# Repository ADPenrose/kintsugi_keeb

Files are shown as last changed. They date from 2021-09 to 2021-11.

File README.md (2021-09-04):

# KINTSUGI
Repository for the kintsugi keyboard.

## Licence
  
Kintsugi is [licenced](LICENSE) under the [Creative Commons Attribution-NonCommercial 4.0 International License](https://creativecommons.org/licenses/by-nc/4.0/).  

This PCB design may be freely reproduced, modified, and manufactured for **PERSONAL USE ONLY** and may not be reproduced in physical form for public sale without the knowledge and permission of me, the desiger of the keyboard. 

That is to say, if you want to run a a public groupbuy, the non-commercial clause can be waived. For that to happen, please contact me at mysticmetromx@gmail.com.

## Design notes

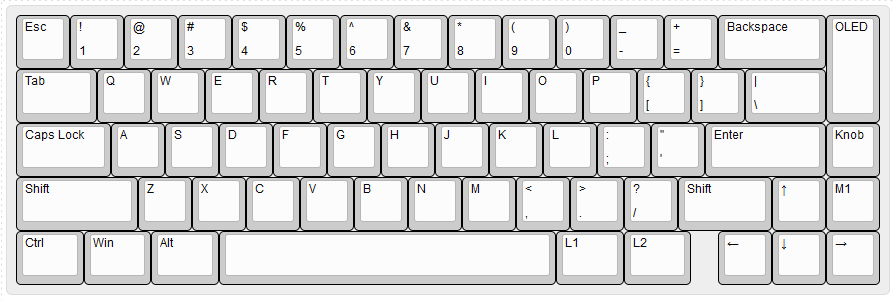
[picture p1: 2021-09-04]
images/Layout.PNG

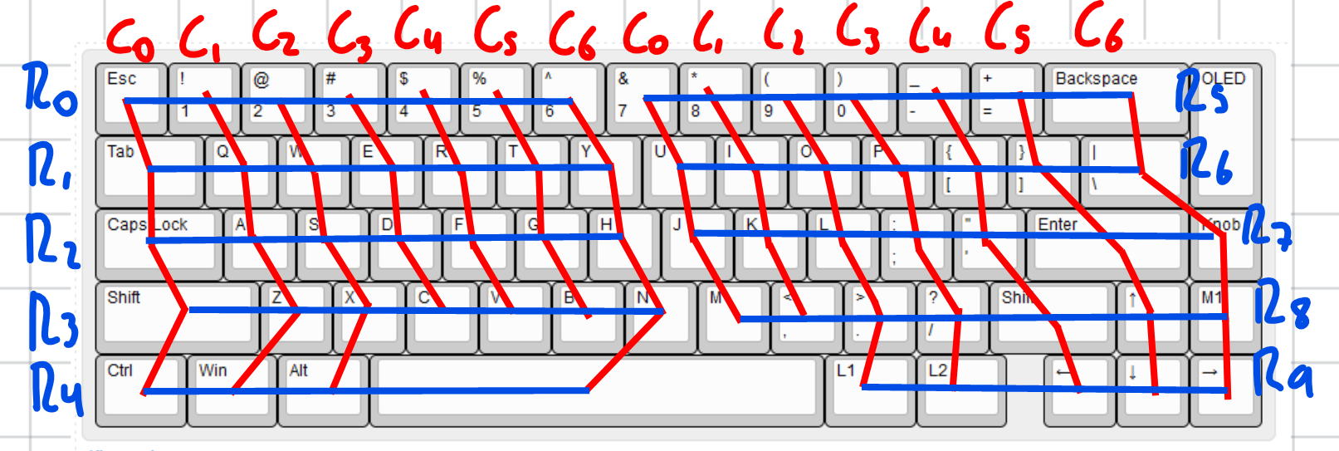
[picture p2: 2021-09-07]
images/Matrix.PNG

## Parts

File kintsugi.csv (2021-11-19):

Id | Designator | Package | Quantity | Designation | Supplier and ref
1 | G*** | LogoKC1 | 1 | LOGO
2 | MX28,MX15 | MXOnly-1.5U-Hotswap | 2 | MX-NoLED
3 | MX39,MX48,MX5,MX1,MX52,MX27,MX13,MX26,MX40,MX55,MX64,MX63,MX62,MX54,MX51,MX50,MX49,MX47,MX46,MX45,MX44,MX43,MX38,MX37,MX36,MX35,MX34,MX33,MX32,MX31,MX30,MX25,MX24,MX23,MX22,MX21,MX20,MX19,MX18,MX17,MX16,MX12,MX11,MX10,MX9,MX8,MX7,MX6,MX4,MX3,MX2 | MXOnly-1U-Hotswap | 51 | MX-NoLED
4 | MX41,MX42 | MXOnly-2.25U-Hotswap | 2 | MX-NoLED
5 | MX53,MX29 | MXOnly-1.75U-Hotswap | 2 | MX-NoLED
6 | MX14 | MXOnly-2U-Hotswap | 1 | MX-NoLED
7 | D54,D53,D28,D27,D14,D13,D15,D65,D64,D63,D62,D61,D60,D59,D58,D57,D56,D55,D52,D51,D50,D49,D48,D47,D46,D45,D44,D43,D42,D41,D40,D39,D38,D37,D36,D35,D34,D33,D32,D31,D30,D29,D26,D25,D24,D23,D22,D21,D20,D19,D18,D17,D16,D12,D11,D10,D9,D8,D7,D6,D5,D4,D3,D2,D1 | Diode-dual-onesided | 65 | D_Small
8 | J1 | PinHeader_1x04_P2.54mm_Vertical | 1 | Conn_01x04
9 | MX58,MX61,MX60,MX57,MX56 | MXOnly-1.25U-Hotswap | 5 | MX-NoLED
10 | MX59 | MXOnly-6.25U-Hotswap-ReversedStabilizers | 1 | MX-NoLED
11 | U1 | Elite-C | 1 | Elite-C
12 | SW1 | RotaryEncoder_Alps_EC11E-Switch_Vertical_H20mm | 1 | Rotary_Encoder_Switch
13 | D81,D80,D79,D78,D77,D76,D75,D74,D73,D72,D71,D70,D69,D68,D67,D66 | LED_WS2812B_PLCC4_5.0x5.0mm_P3.2mm | 16 | WS2812B
14 | C16,C15,C14,C13,C12,C11,C10,C9,C8,C7,C6,C5,C4,C3,C2,C1 | C_0805_2012Metric_Pad1.18x1.45mm_HandSolder | 16 | 100n

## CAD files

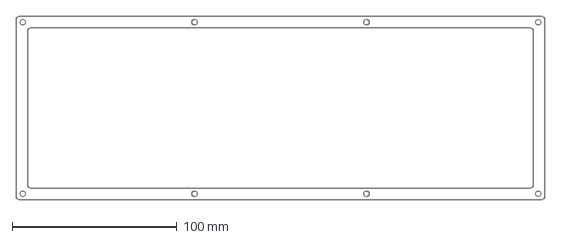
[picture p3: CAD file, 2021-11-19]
acrylic_case/DXF/kintsugi_closed_upper.dxf
320.8 x 111.2 mm

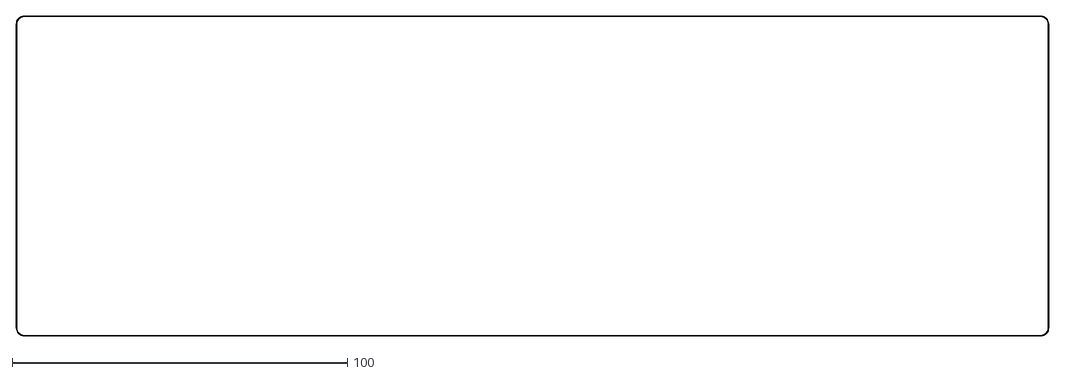
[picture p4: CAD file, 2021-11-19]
dfx/kintsugi-Edge_Cuts.dxf
308.0 x 95.3

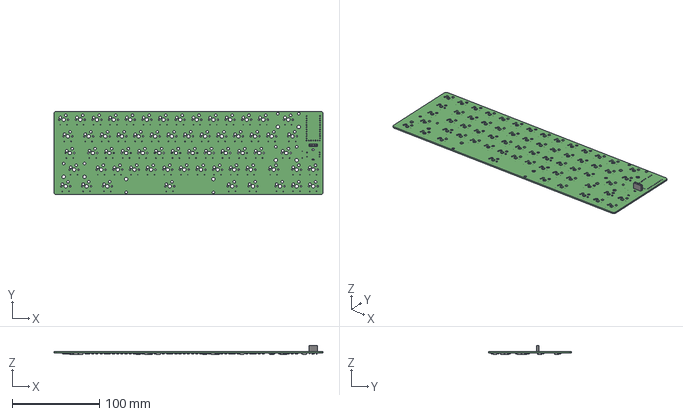
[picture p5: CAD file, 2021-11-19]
kintsugi.step
308.0 x 95.2 x 10.3 mm

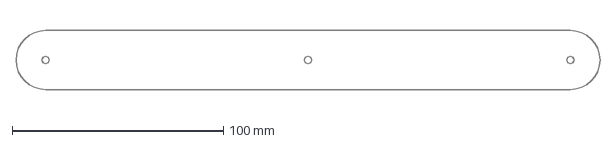
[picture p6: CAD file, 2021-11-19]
acrylic_case/DXF/kintsugi_foot_1.dxf
276.5 x 28.0 mm

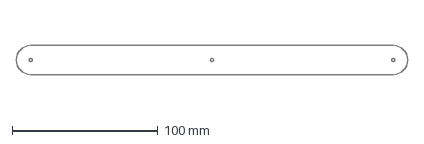
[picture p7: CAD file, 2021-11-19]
acrylic_case/DXF/kintsugi_foot_3.dxf
268.5 x 20.0 mm

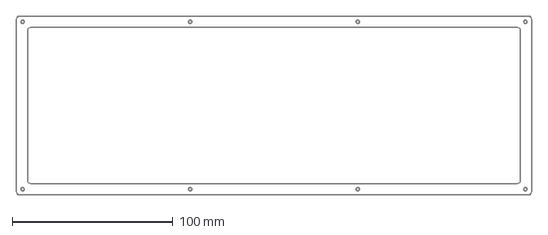
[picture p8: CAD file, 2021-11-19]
acrylic_case/DXF/kintsugi_top.dxf
320.8 x 111.2 mm

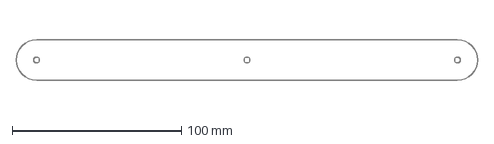
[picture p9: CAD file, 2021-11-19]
acrylic_case/DXF/kintsugi_foot_2.dxf
272.5 x 24.0 mm

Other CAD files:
acrylic_case/DWG/kintsugi_closed_lower.dwg
acrylic_case/HSMCU/3mm_acrilico_azul_pastel.dwg
acrylic_case/Para corte/2_3mm_acrilico_espejo_dorado.dwg
acrylic_case/DWG/kintsugi_open_upper.dwg
acrylic_case/HSMCU/1.5mm_bicolam_abs_blanco.dwg
acrylic_case/Para corte/5_3mm_acrilico_cristal_mate.dwg
acrylic_case/DWG/Kintsugi_case.dwg
acrylic_case/Para corte/7_3mm_acrilico_cristal_mate.dwg
acrylic_case/DWG/kintsugi_plate.dwg
acrylic_case/Para corte/3_1.5mm_bicolam_abs_negro.dwg
acrylic_case/DWG/kintsugi_bottom.dwg
acrylic_case/DWG/kintsugi_closed_upper.dwg
acrylic_case/DWG/kintsugi_foot_1.dwg
acrylic_case/DWG/kintsugi_foot_2.dwg
acrylic_case/DWG/kintsugi_foot_3.dwg
acrylic_case/DWG/kintsugi_open_lower.dwg
acrylic_case/DWG/kintsugi_top.dwg
acrylic_case/DXF/kintsugi_open_lower.dxf
acrylic_case/Para corte/1_3mm_acrilico_cristal_mate.dwg
acrylic_case/Para corte/4_3mm_acrilico_cristal_mate.dwg
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

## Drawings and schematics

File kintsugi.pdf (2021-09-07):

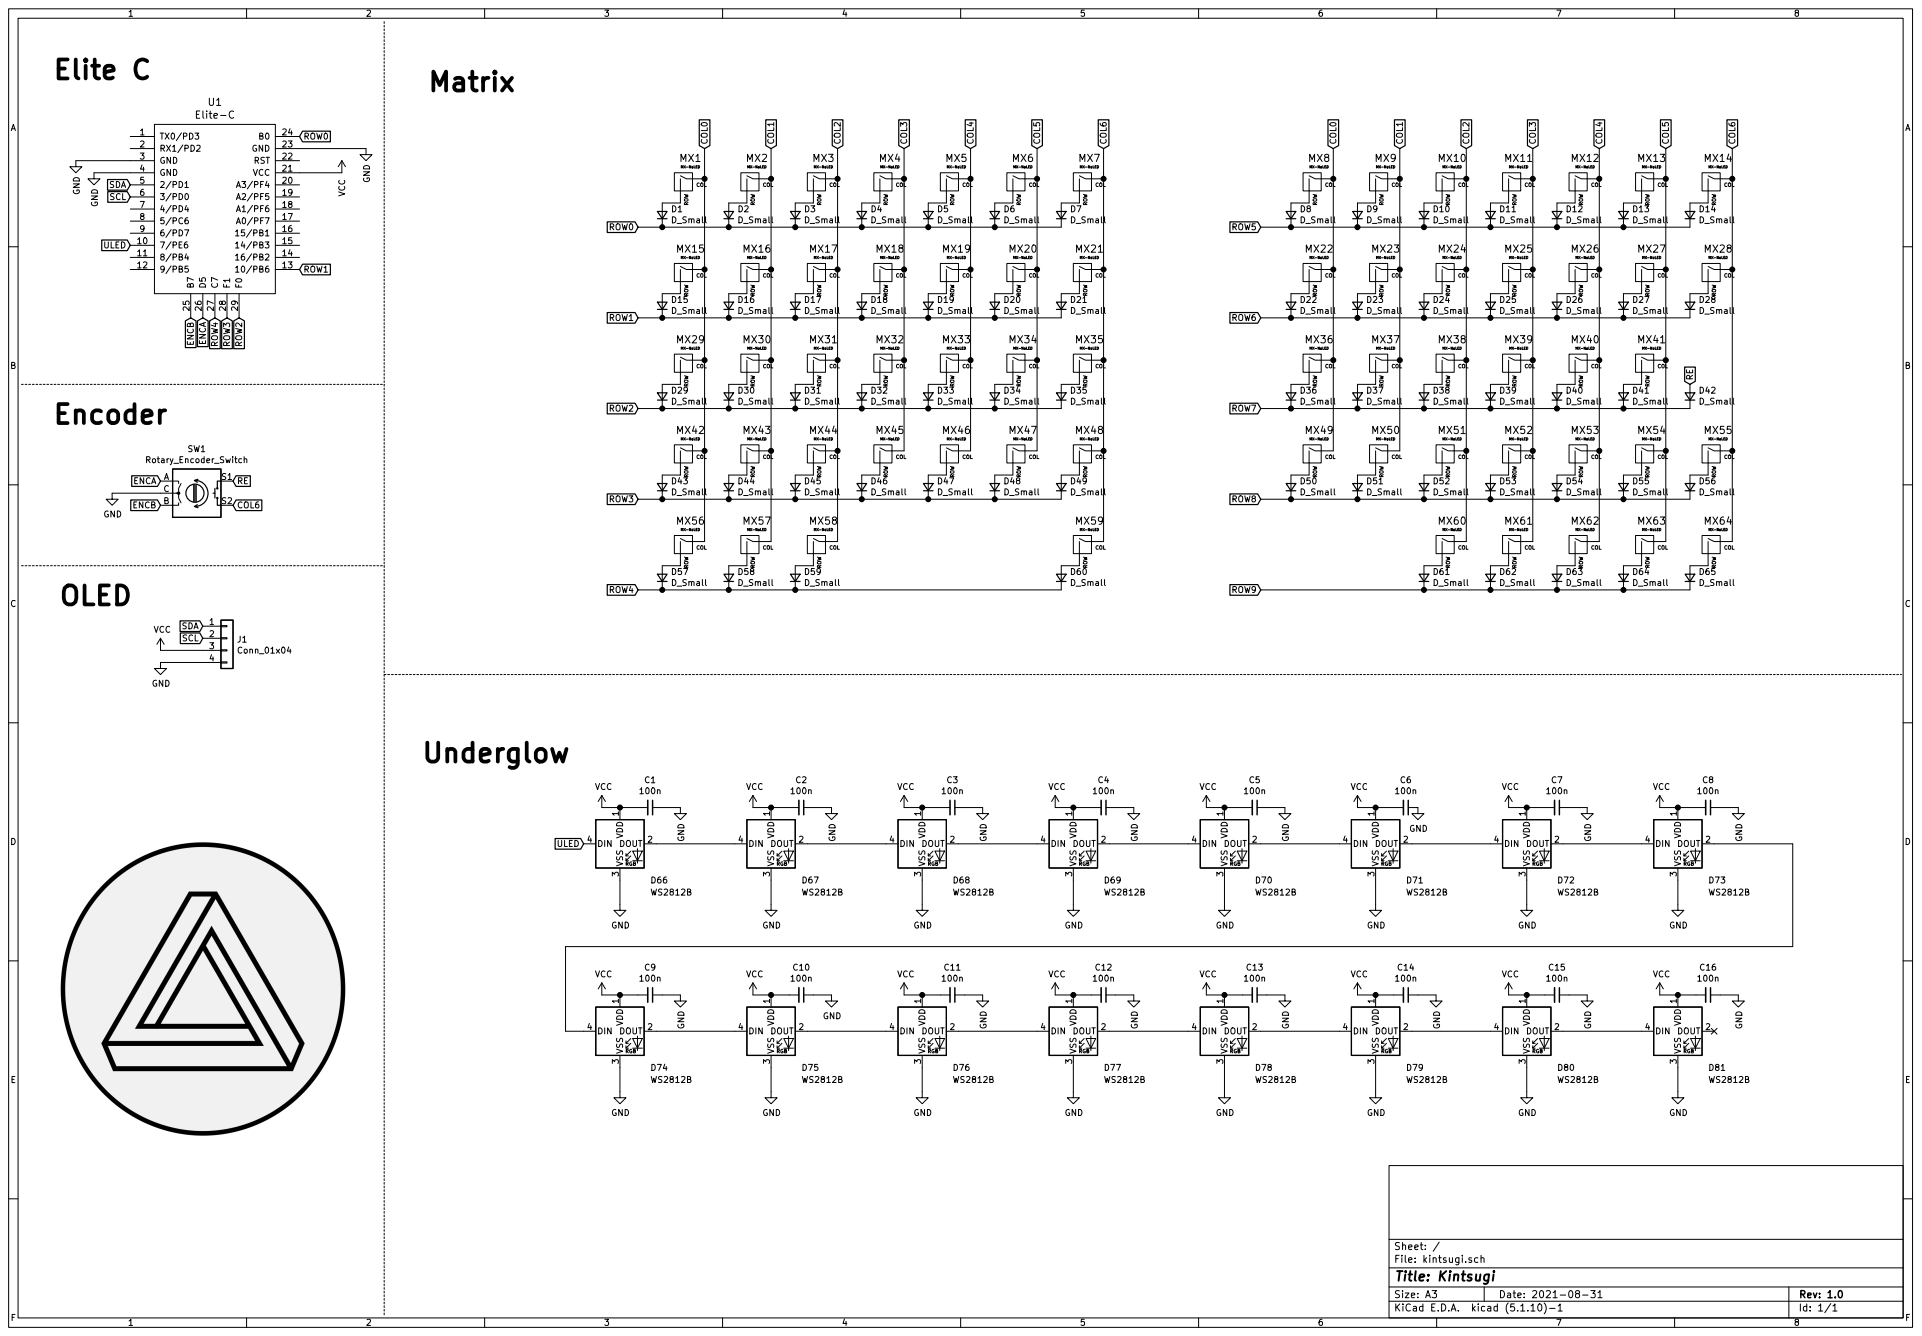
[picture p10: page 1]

MX-NoLED D3D_Small COL ROW MX3

MX-NoLED COL ROW MX8
MX-NoLED D12 D_Small COL ROW MX22

MX-NoLED D13 D_Small COL ROW MX52

MX-NoLED D28 D_Small COL ROW MX14

MX-NoLED D18 D_Small COL ROW MX18

MX-NoLED D30 D_Small COL ROW MX30

MX-NoLED D34 D_Small COL ROW MX34

MX-NoLED COL ROW MX38

MX-NoLED COL ROW MX42

COL ROW MX46
MX-NoLED D51 D_Small RGB VDD

COL ROW MX51
MX-NoLED D55 D_Small COL ROW MX60

MX-NoLED COL ROW MX56

MX-NoLED RGB VDD

MX-NoLED D64 D_Small RGB VDD

File: kintsugi.sch Sheet: /
Id: 1/1 Title: Kintsugi

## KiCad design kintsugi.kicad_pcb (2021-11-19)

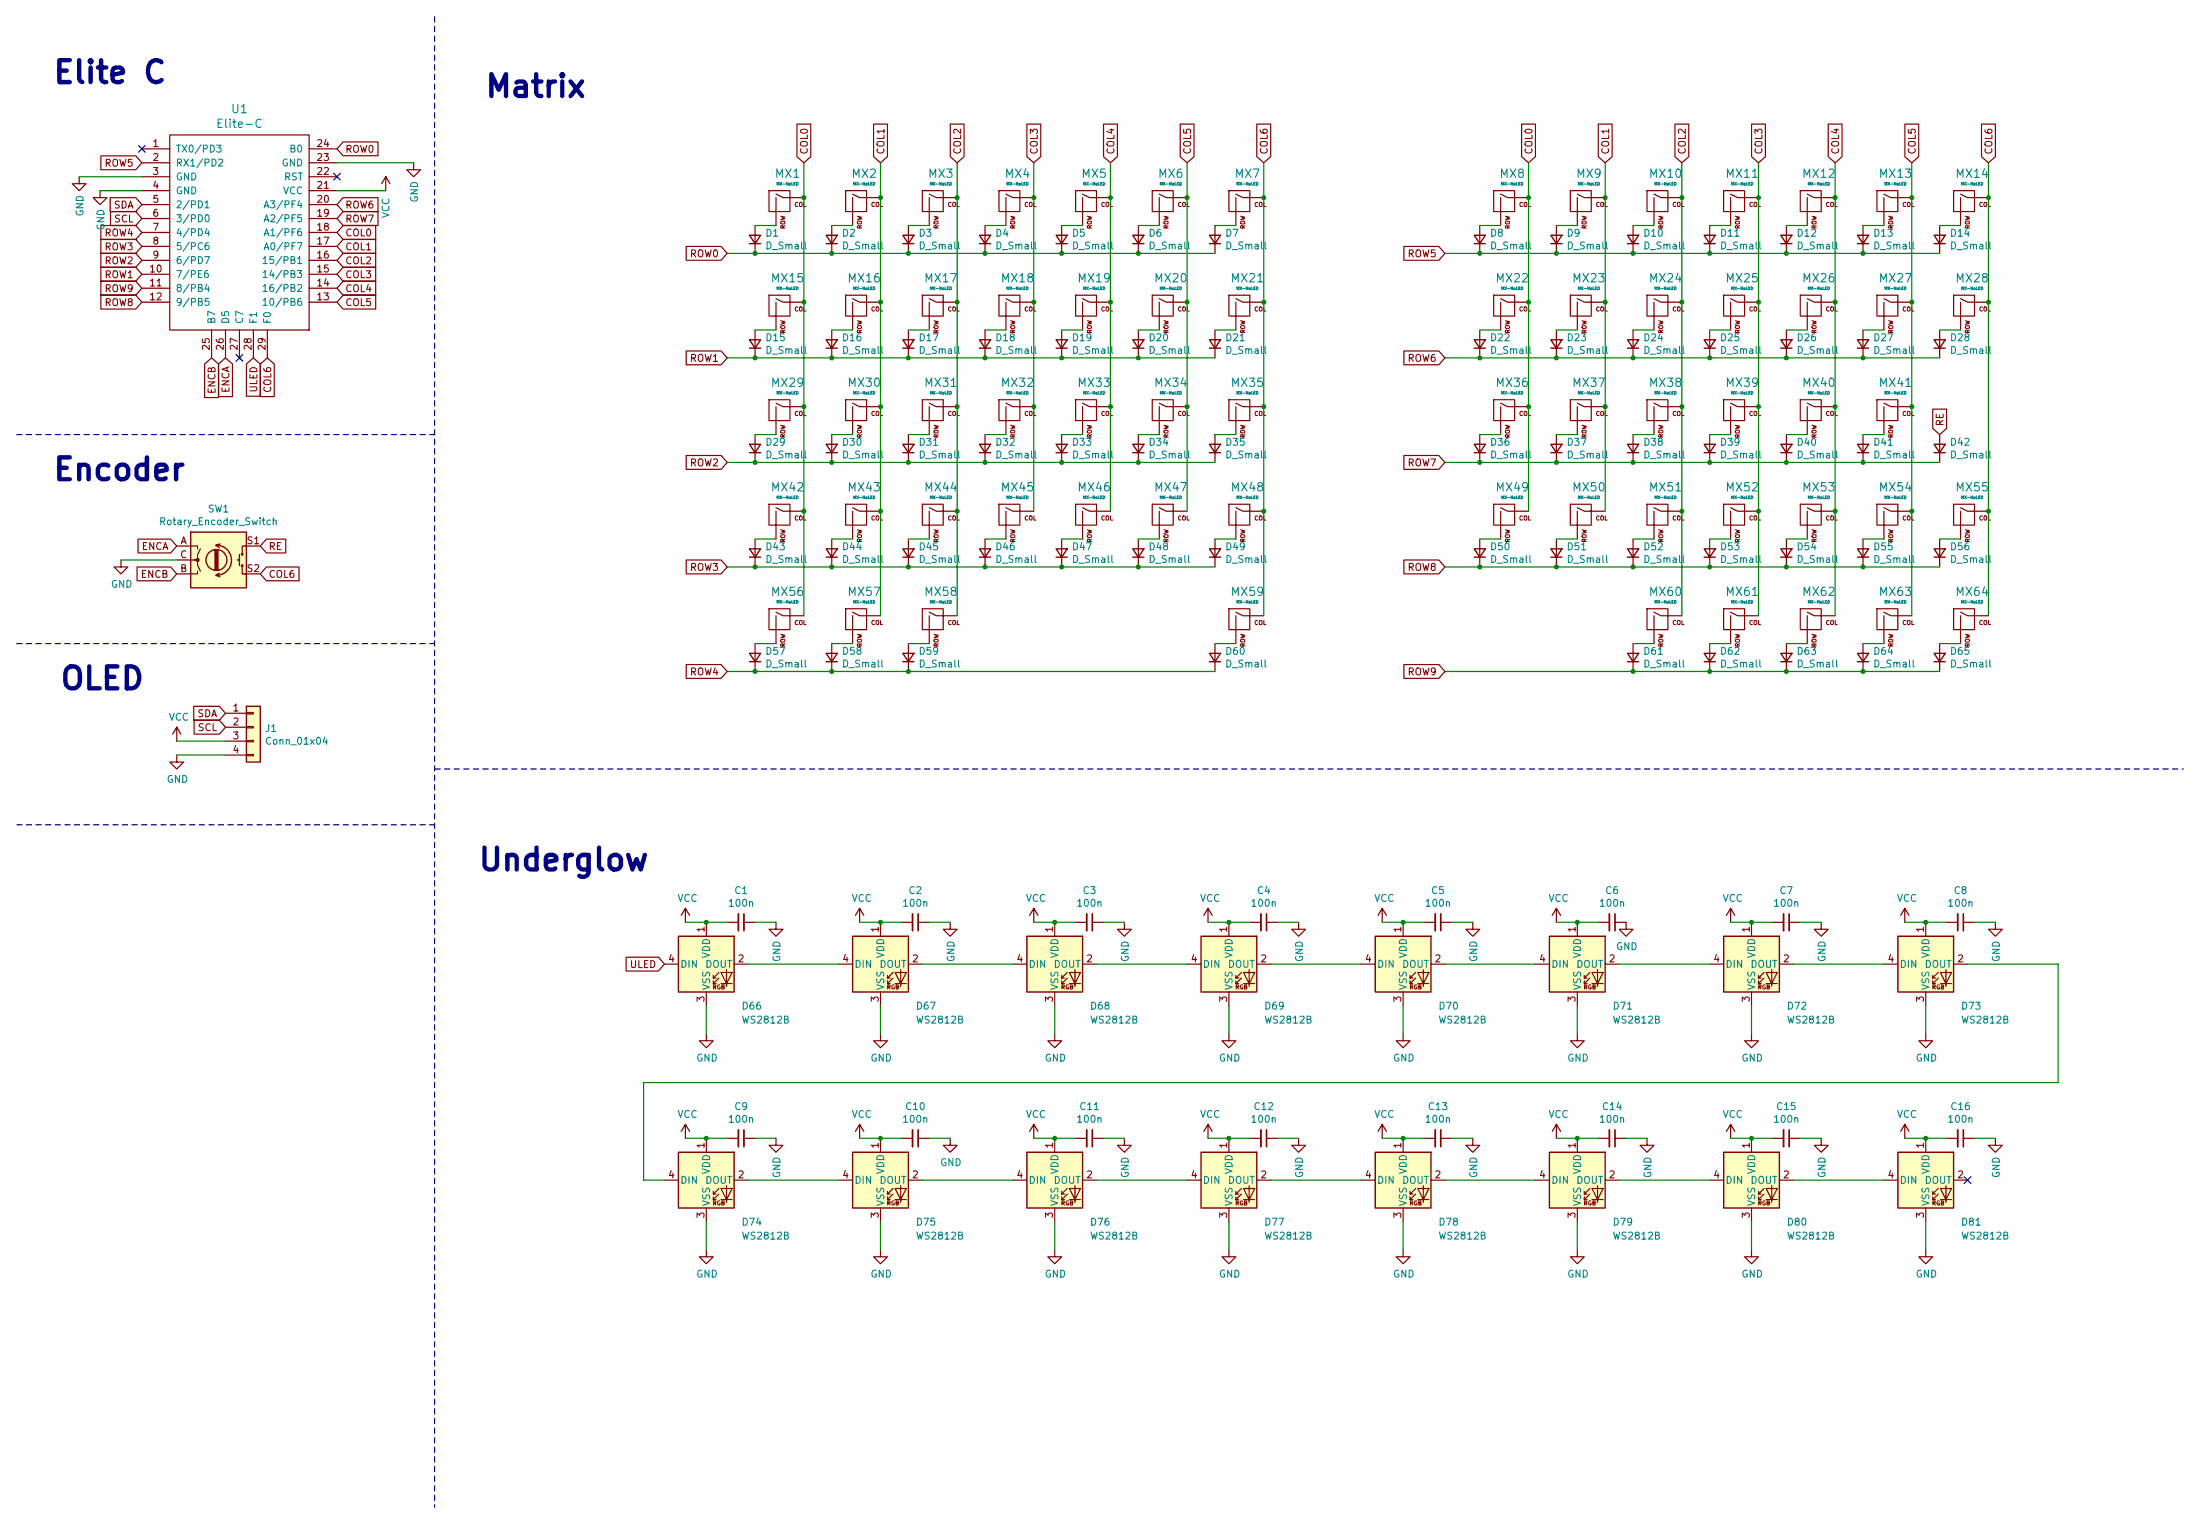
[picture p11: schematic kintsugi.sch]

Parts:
C1, C2, C3, C4, C5, C6, C7, C8, C9, C10, C11, C12, C13, C14, C15, C16: 100n; C_0805_2012Metric_Pad1.18x1.45mm_HandSolder
D1, D2, D3, D4, D5, D6, D7, D8, D9, D10, D11, D12, D13, D14, D15, D16, D17, D18, D19, D20, D21, D22, D23, D24, D25, D26, D27, D28, D29, D30, D31, D32, D33, D34, D35, D36, D37, D38, D39, D40, D41, D42, D43, D44, D45, D46, D47, D48, D49, D50, D51, D52, D53, D54, D55, D56, D57, D58, D59, D60, D61, D62, D63, D64, D65: D_Small; Diode-dual-onesided
D66, D67, D68, D69, D70, D71, D72, D73, D74, D75, D76, D77, D78, D79, D80, D81: WS2812B; LED_WS2812B_PLCC4_5.0x5.0mm_P3.2mm
J1: Conn_01x04; PinHeader_1x04_P2.54mm_Vertical
MX1, MX2, MX3, MX4, MX5, MX6, MX7, MX8, MX9, MX10, MX11, MX12, MX13, MX16, MX17, MX18, MX19, MX20, MX21, MX22, MX23, MX24, MX25, MX26, MX27, MX30, MX31, MX32, MX33, MX34, MX35, MX36, MX37, MX38, MX39, MX40, MX43, MX44, MX45, MX46, MX47, MX48, MX49, MX50, MX51, MX52, MX54, MX55, MX62, MX63, MX64: MX-NoLED; MXOnly-1U-Hotswap
MX14: MX-NoLED; MXOnly-2U-Hotswap
MX15, MX28: MX-NoLED; MXOnly-1.5U-Hotswap
MX29, MX53: MX-NoLED; MXOnly-1.75U-Hotswap
MX41, MX42: MX-NoLED; MXOnly-2.25U-Hotswap
MX56, MX57, MX58, MX60, MX61: MX-NoLED; MXOnly-1.25U-Hotswap
MX59: MX-NoLED; MXOnly-6.25U-Hotswap-ReversedStabilizers
SW1: Rotary_Encoder_Switch; RotaryEncoder_Alps_EC11E-Switch_Vertical_H20mm
U1: Elite-C

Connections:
COL0: MX1.1 (COL), MX8.1 (COL), MX15.1 (COL), MX22.1 (COL), MX29.1 (COL), MX36.1 (COL), MX42.1 (COL), MX49.1 (COL), MX56.1 (COL), U1.18 (A1/PF6)
COL1: MX2.1 (COL), MX9.1 (COL), MX16.1 (COL), MX23.1 (COL), MX30.1 (COL), MX37.1 (COL), MX43.1 (COL), MX50.1 (COL), MX57.1 (COL), U1.17 (A0/PF7)
COL2: MX3.1 (COL), MX10.1 (COL), MX17.1 (COL), MX24.1 (COL), MX31.1 (COL), MX38.1 (COL), MX44.1 (COL), MX51.1 (COL), MX58.1 (COL), MX60.1 (COL), U1.16 (15/PB1)
COL3: MX4.1 (COL), MX11.1 (COL), MX18.1 (COL), MX25.1 (COL), MX32.1 (COL), MX39.1 (COL), MX45.1 (COL), MX52.1 (COL), MX61.1 (COL), U1.15 (14/PB3)
COL4: MX5.1 (COL), MX12.1 (COL), MX19.1 (COL), MX26.1 (COL), MX33.1 (COL), MX40.1 (COL), MX46.1 (COL), MX53.1 (COL), MX62.1 (COL), U1.14 (16/PB2)
COL5: MX6.1 (COL), MX13.1 (COL), MX20.1 (COL), MX27.1 (COL), MX34.1 (COL), MX41.1 (COL), MX47.1 (COL), MX54.1 (COL), MX63.1 (COL), U1.13 (10/PB6)
COL6: MX7.1 (COL), MX14.1 (COL), MX21.1 (COL), MX28.1 (COL), MX35.1 (COL), MX48.1 (COL), MX55.1 (COL), MX59.1 (COL), MX64.1 (COL), SW1.S2, U1.29 (F0)
ENCA: SW1.A, U1.26 (D5)
ENCB: SW1.B, U1.25 (B7)
GND: C1.1, C2.1, C3.1, C4.1, C5.1, C6.1, C7.1, C8.1, C9.1, C10.1, C11.1, C12.1, C13.1, C14.1, C15.1, C16.1, D66.3 (VSS), D67.3 (VSS), D68.3 (VSS), D69.3 (VSS), D70.3 (VSS), D71.3 (VSS), D72.3 (VSS), D73.3 (VSS), D74.3 (VSS), D75.3 (VSS), D76.3 (VSS), D77.3 (VSS), D78.3 (VSS), D79.3 (VSS), D80.3 (VSS), D81.3 (VSS), J1.4, SW1.C, U1.3 (GND), U1.4 (GND), U1.23 (GND)
unnamed: D1.2 (A), MX1.2 (ROW)
unnamed: D2.2 (A), MX2.2 (ROW)
unnamed: D3.2 (A), MX3.2 (ROW)
unnamed: D4.2 (A), MX4.2 (ROW)
unnamed: D5.2 (A), MX5.2 (ROW)
unnamed: D6.2 (A), MX6.2 (ROW)
unnamed: D7.2 (A), MX7.2 (ROW)
unnamed: D8.2 (A), MX8.2 (ROW)
unnamed: D9.2 (A), MX9.2 (ROW)
unnamed: D10.2 (A), MX10.2 (ROW)
unnamed: D11.2 (A), MX11.2 (ROW)
unnamed: D12.2 (A), MX12.2 (ROW)
unnamed: D13.2 (A), MX13.2 (ROW)
unnamed: D14.2 (A), MX14.2 (ROW)
unnamed: D15.2 (A), MX15.2 (ROW)
unnamed: D16.2 (A), MX16.2 (ROW)
unnamed: D17.2 (A), MX17.2 (ROW)
unnamed: D18.2 (A), MX18.2 (ROW)
unnamed: D19.2 (A), MX19.2 (ROW)
unnamed: D20.2 (A), MX20.2 (ROW)
unnamed: D21.2 (A), MX21.2 (ROW)
unnamed: D22.2 (A), MX22.2 (ROW)
unnamed: D23.2 (A), MX23.2 (ROW)
unnamed: D24.2 (A), MX24.2 (ROW)
unnamed: D25.2 (A), MX25.2 (ROW)
unnamed: D26.2 (A), MX26.2 (ROW)
unnamed: D27.2 (A), MX27.2 (ROW)
unnamed: D28.2 (A), MX28.2 (ROW)
unnamed: D29.2 (A), MX29.2 (ROW)
unnamed: D30.2 (A), MX30.2 (ROW)
unnamed: D31.2 (A), MX31.2 (ROW)
unnamed: D32.2 (A), MX32.2 (ROW)
unnamed: D33.2 (A), MX33.2 (ROW)
unnamed: D34.2 (A), MX34.2 (ROW)
unnamed: D35.2 (A), MX35.2 (ROW)
unnamed: D36.2 (A), MX36.2 (ROW)
unnamed: D37.2 (A), MX37.2 (ROW)
unnamed: D38.2 (A), MX38.2 (ROW)
unnamed: D39.2 (A), MX39.2 (ROW)
unnamed: D40.2 (A), MX40.2 (ROW)
unnamed: D41.2 (A), MX41.2 (ROW)
unnamed: D43.2 (A), MX42.2 (ROW)
unnamed: D44.2 (A), MX43.2 (ROW)
unnamed: D45.2 (A), MX44.2 (ROW)
unnamed: D46.2 (A), MX45.2 (ROW)
unnamed: D47.2 (A), MX46.2 (ROW)
unnamed: D48.2 (A), MX47.2 (ROW)
unnamed: D49.2 (A), MX48.2 (ROW)
unnamed: D50.2 (A), MX49.2 (ROW)
unnamed: D51.2 (A), MX50.2 (ROW)
unnamed: D52.2 (A), MX51.2 (ROW)
unnamed: D53.2 (A), MX52.2 (ROW)
unnamed: D54.2 (A), MX53.2 (ROW)
unnamed: D55.2 (A), MX54.2 (ROW)
unnamed: D56.2 (A), MX55.2 (ROW)
unnamed: D57.2 (A), MX56.2 (ROW)
unnamed: D58.2 (A), MX57.2 (ROW)
unnamed: D59.2 (A), MX58.2 (ROW)
unnamed: D60.2 (A), MX59.2 (ROW)
unnamed: D61.2 (A), MX60.2 (ROW)
unnamed: D62.2 (A), MX61.2 (ROW)
unnamed: D63.2 (A), MX62.2 (ROW)
unnamed: D64.2 (A), MX63.2 (ROW)
unnamed: D65.2 (A), MX64.2 (ROW)
unnamed: D66.2 (DOUT), D67.4 (DIN)
unnamed: D67.2 (DOUT), D68.4 (DIN)
unnamed: D68.2 (DOUT), D69.4 (DIN)
unnamed: D69.2 (DOUT), D70.4 (DIN)
unnamed: D70.2 (DOUT), D71.4 (DIN)
unnamed: D71.2 (DOUT), D72.4 (DIN)
unnamed: D72.2 (DOUT), D73.4 (DIN)
unnamed: D73.2 (DOUT), D74.4 (DIN)
unnamed: D74.2 (DOUT), D75.4 (DIN)
unnamed: D75.2 (DOUT), D76.4 (DIN)
unnamed: D76.2 (DOUT), D77.4 (DIN)
unnamed: D77.2 (DOUT), D78.4 (DIN)
unnamed: D78.2 (DOUT), D79.4 (DIN)
unnamed: D79.2 (DOUT), D80.4 (DIN)
unnamed: D80.2 (DOUT), D81.4 (DIN)
RE: D42.2 (A), SW1.S1
ROW0: D1.1 (K), D2.1 (K), D3.1 (K), D4.1 (K), D5.1 (K), D6.1 (K), D7.1 (K), U1.24 (B0)
ROW1: D15.1 (K), D16.1 (K), D17.1 (K), D18.1 (K), D19.1 (K), D20.1 (K), D21.1 (K), U1.10 (7/PE6)
ROW2: D29.1 (K), D30.1 (K), D31.1 (K), D32.1 (K), D33.1 (K), D34.1 (K), D35.1 (K), U1.9 (6/PD7)
ROW3: D43.1 (K), D44.1 (K), D45.1 (K), D46.1 (K), D47.1 (K), D48.1 (K), D49.1 (K), U1.8 (5/PC6)
ROW4: D57.1 (K), D58.1 (K), D59.1 (K), D60.1 (K), U1.7 (4/PD4)
ROW5: D8.1 (K), D9.1 (K), D10.1 (K), D11.1 (K), D12.1 (K), D13.1 (K), D14.1 (K), U1.2 (RX1/PD2)
ROW6: D22.1 (K), D23.1 (K), D24.1 (K), D25.1 (K), D26.1 (K), D27.1 (K), D28.1 (K), U1.20 (A3/PF4)
ROW7: D36.1 (K), D37.1 (K), D38.1 (K), D39.1 (K), D40.1 (K), D41.1 (K), D42.1 (K), U1.19 (A2/PF5)
ROW8: D50.1 (K), D51.1 (K), D52.1 (K), D53.1 (K), D54.1 (K), D55.1 (K), D56.1 (K), U1.12 (9/PB5)
ROW9: D61.1 (K), D62.1 (K), D63.1 (K), D64.1 (K), D65.1 (K), U1.11 (8/PB4)
SCL: J1.2, U1.6 (3/PD0)
SDA: J1.1, U1.5 (2/PD1)
ULED: D66.4 (DIN), U1.28 (F1)
VCC: C1.2, C2.2, C3.2, C4.2, C5.2, C6.2, C7.2, C8.2, C9.2, C10.2, C11.2, C12.2, C13.2, C14.2, C15.2, C16.2, D66.1 (VDD), D67.1 (VDD), D68.1 (VDD), D69.1 (VDD), D70.1 (VDD), D71.1 (VDD), D72.1 (VDD), D73.1 (VDD), D74.1 (VDD), D75.1 (VDD), D76.1 (VDD), D77.1 (VDD), D78.1 (VDD), D79.1 (VDD), D80.1 (VDD), D81.1 (VDD), J1.3, U1.21 (VCC)

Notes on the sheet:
Elite C
Encoder
OLED
Underglow
Matrix

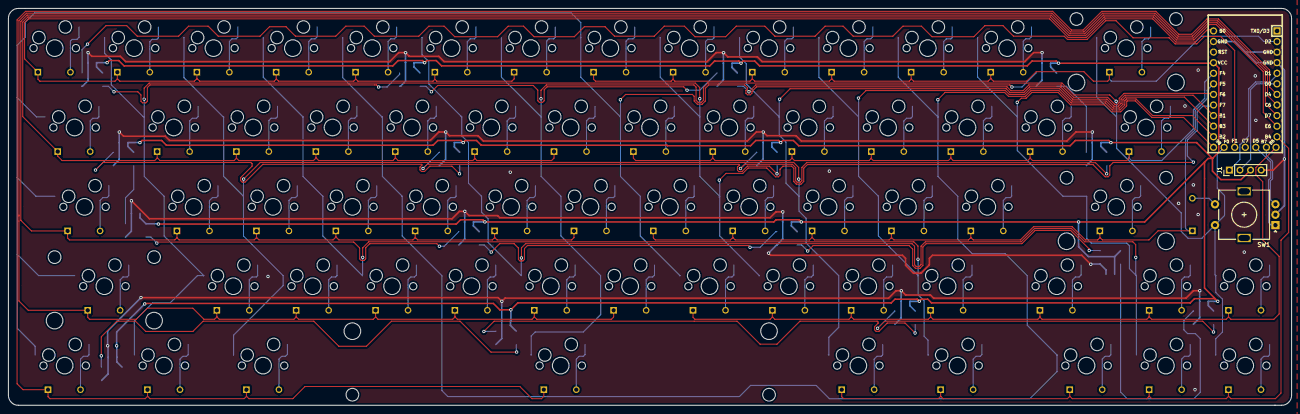
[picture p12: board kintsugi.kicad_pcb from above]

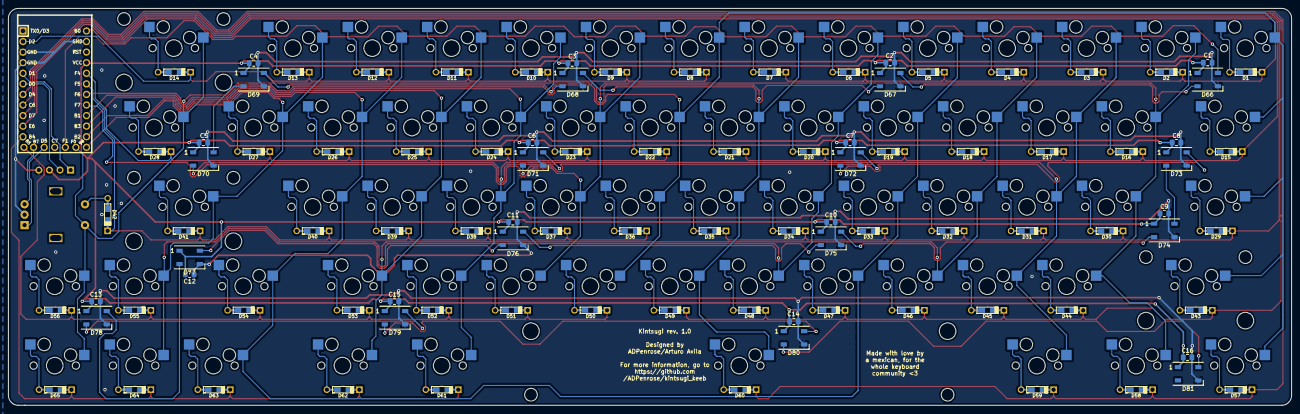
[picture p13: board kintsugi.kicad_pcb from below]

Board: 2 copper layers, 308.0 x 95.2 mm, 164 parts (98 on the bottom side), 104 nets.

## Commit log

2021-08-29 Add submodules
    [kintsugi.kicad_pcb, kintsugi.sch]
2021-08-29 First commit
    Added Elite C and initial switch and diodes matrix symbols.
2021-09-04 Footprints added
    First revision of the schematic finished and footprints added.
    [kintsugi.sch]
2021-09-05 Routing started
    Began routing rows and columns
    [kintsugi.kicad_pcb, kintsugi.sch]
2021-09-06 Columns and rows connected
    Switches connected to their respective row and column
    [kintsugi.kicad_pcb, kintsugi.sch]
2021-09-06 Deleted old routing
    Fresh start
    [kintsugi.kicad_pcb]
2021-09-07 Routed rows and first three columns
    Began routing the new pcb.
    [kintsugi.kicad_pcb, kintsugi.sch]
2021-09-08 Re-routed rows, cols, oled and encoder
    Routed for the third time the board, rows in front, cols in back.
    [kintsugi.kicad_pcb, kintsugi.sch]
2021-09-08 Began routing leds
    Started with the underglows routing
    [kintsugi.kicad_pcb]
2021-09-11 Routed first 5 rows
    Finished routing leds and first 5 rows
    [kintsugi.kicad_pcb, kintsugi.sch]
2021-09-11 Finished routing and gnd fill
    First revision completed, waiting for review
    [kintsugi.kicad_pcb, kintsugi.sch]
2021-09-11 Added silkscreen logos
    Almost there
    [kintsugi.kicad_pcb]
2021-09-12 Gerber files generated
    I think this is where it ends
    [kintsugi-B_Cu.gbr, kintsugi-B_Mask.gbr, kintsugi-B_Paste.gbr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]
2021-11-19 Case
    Added proto case files
    [1_3mm_acrilico_cristal_mate.dwg, 2_3mm_acrilico_espejo_dorado.dwg, 3_1.5mm_bicolam_abs_negro.dwg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]
2022-06-10 Added fixed case files. Pending review.
    [1_3mm_acrilico_cristal_mate.dwg, 2_3mm_acrilico_espejo_dorado.dwg, 3_1.5mm_bicolam_abs_negro.dwg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]
2022-06-16 Addeds v2 of the case.
    [1.5mm_bicolam_abs_blanco.dwg, 3mm_acrilico_azul_pastel.dwg]
